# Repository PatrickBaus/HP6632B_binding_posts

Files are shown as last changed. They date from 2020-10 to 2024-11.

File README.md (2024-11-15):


# HP 66332A and HP 6632B-6634B Frontpanel Binding Post PCB
This repository contains the schematics for a PCB to mount frontpanel binding post on an [HP 6632B](https://www.keysight.com/us/en/product/6632B/100-watt-system-power-supply-20v-5a.html) (and siblings) power supply. It is an adaption of the original A4 PCB used in option #020 units.

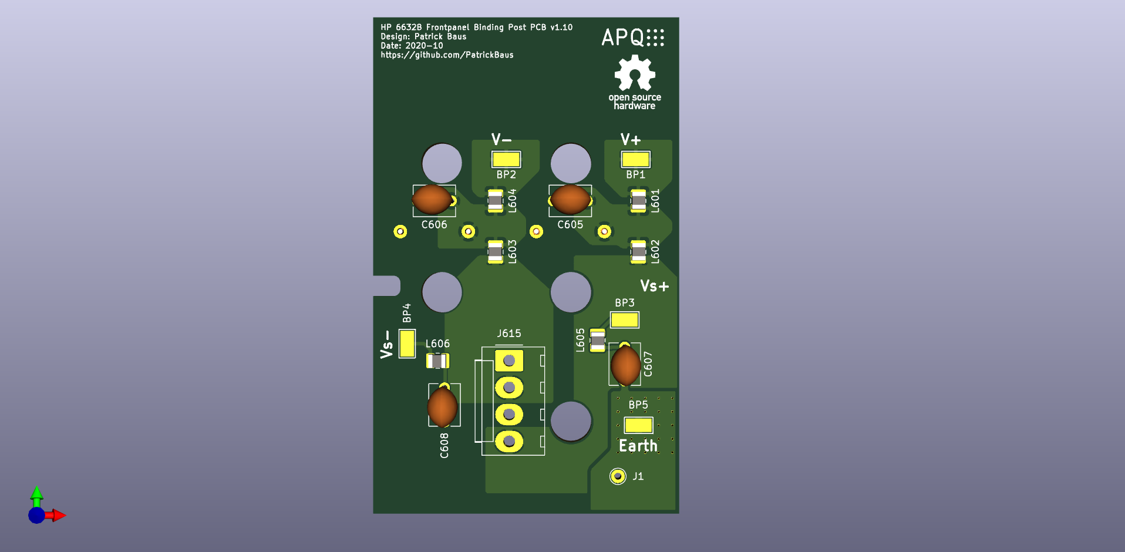
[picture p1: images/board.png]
Front panel binding post PCB


## Contents
- [Introduction](#introduction)
- [Design Files](#design-files)
- [Related Repositories](#related-repositories)
- [Versioning](#versioning)
- [License](#license)

## Introduction
In addition to the original option #20 PCB, this board breaks out the sense connections as well and also the chassis ground. This makes connecting multiple [HP 663xB](https://www.keysight.com/us/en/product/6632B/100-watt-system-power-supply-20v-5a.html) in parallel possible. On the downside, this requires connecting the sense pins externally. To make this easier I also made a small [shorting bar](https://github.com/PatrickBaus/HP6632B_shorting_bar) to easily short the sense terminals to the force terminals directly at the power supply output.

The components chosen allow the board to be used on all variants of the HP 663xB family - even the 100 V 6634B. A variety of different binding posts can be used. There are HP/Agilent versions available on Ebay. I used [Pomona 4243-0](https://www.pomonaelectronics.com/products/hardware/double-binding-post) ([Digikey](https://www.digikey.de/product-detail/de/pomona-electronics/4243-0/501-1126-ND/604321)) and [3760-5](https://www.pomonaelectronics.com/products/hardware/binding-post-tin-plated) ([Digikey](https://www.digikey.de/product-detail/de/pomona-electronics/3760-5/501-1506-ND/736554)) binding posts.

The final result looks like this:
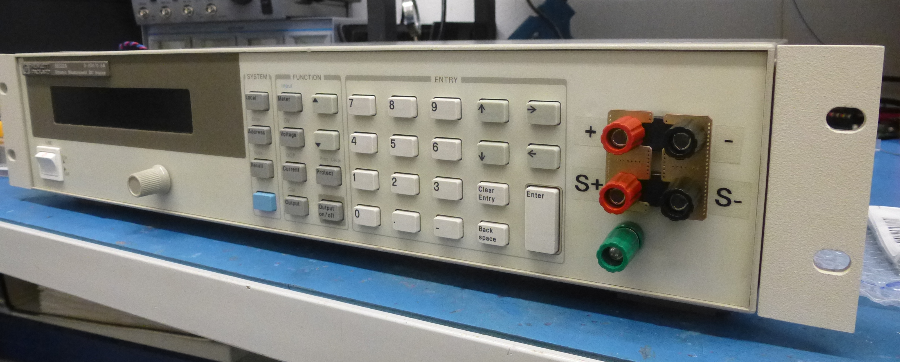
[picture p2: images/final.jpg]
HP 66332A with binding posts


## Design Files
The root folder contains the KiCAD files. The bill of materials can be found on the [releases](../../releases) page along with Gerber files for production.

## Related Repositories
See the following repositories which contain addional optional parts.

- [HP 66332A and HP 6632B-6634B Shorting Bar](https://github.com/PatrickBaus/HP6632B_shorting_bar)

## Versioning
I use [SemVer](http://semver.org/) for versioning. For the versions available, see the [tags](../../tags) available for this repository.

- MAJOR versions in this context mean a breaking change to the external interface of the hardware like different connectors or functions.
- MINOR versions contain changes to the hardware that only affect the inner workings of the circuit, but otherwise the performance is unaffected.
- PATCH versions do not affect the schematics or invalidate older bill of materials. These changes may include updated components (to replace obsolete parts for example), an updated silkscreen, or fixed typos.

## License
This work is released under the CERN-OHL-W
See [https://ohwr.org/cern_ohl_w_v2.pdf](https://ohwr.org/cern_ohl_w_v2.pdf) or the included LICENSE file for more information.

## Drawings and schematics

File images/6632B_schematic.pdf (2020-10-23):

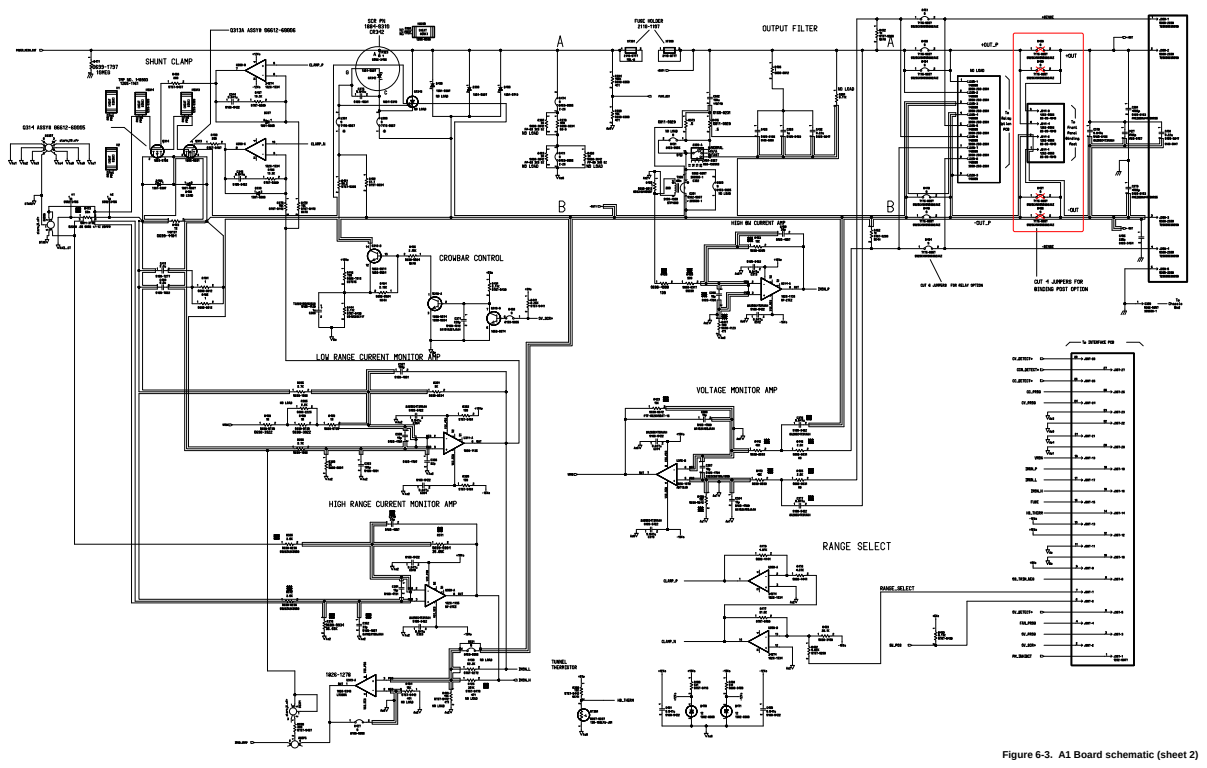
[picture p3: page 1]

Figure 6-3. A1 Board schematic (sheet 2)

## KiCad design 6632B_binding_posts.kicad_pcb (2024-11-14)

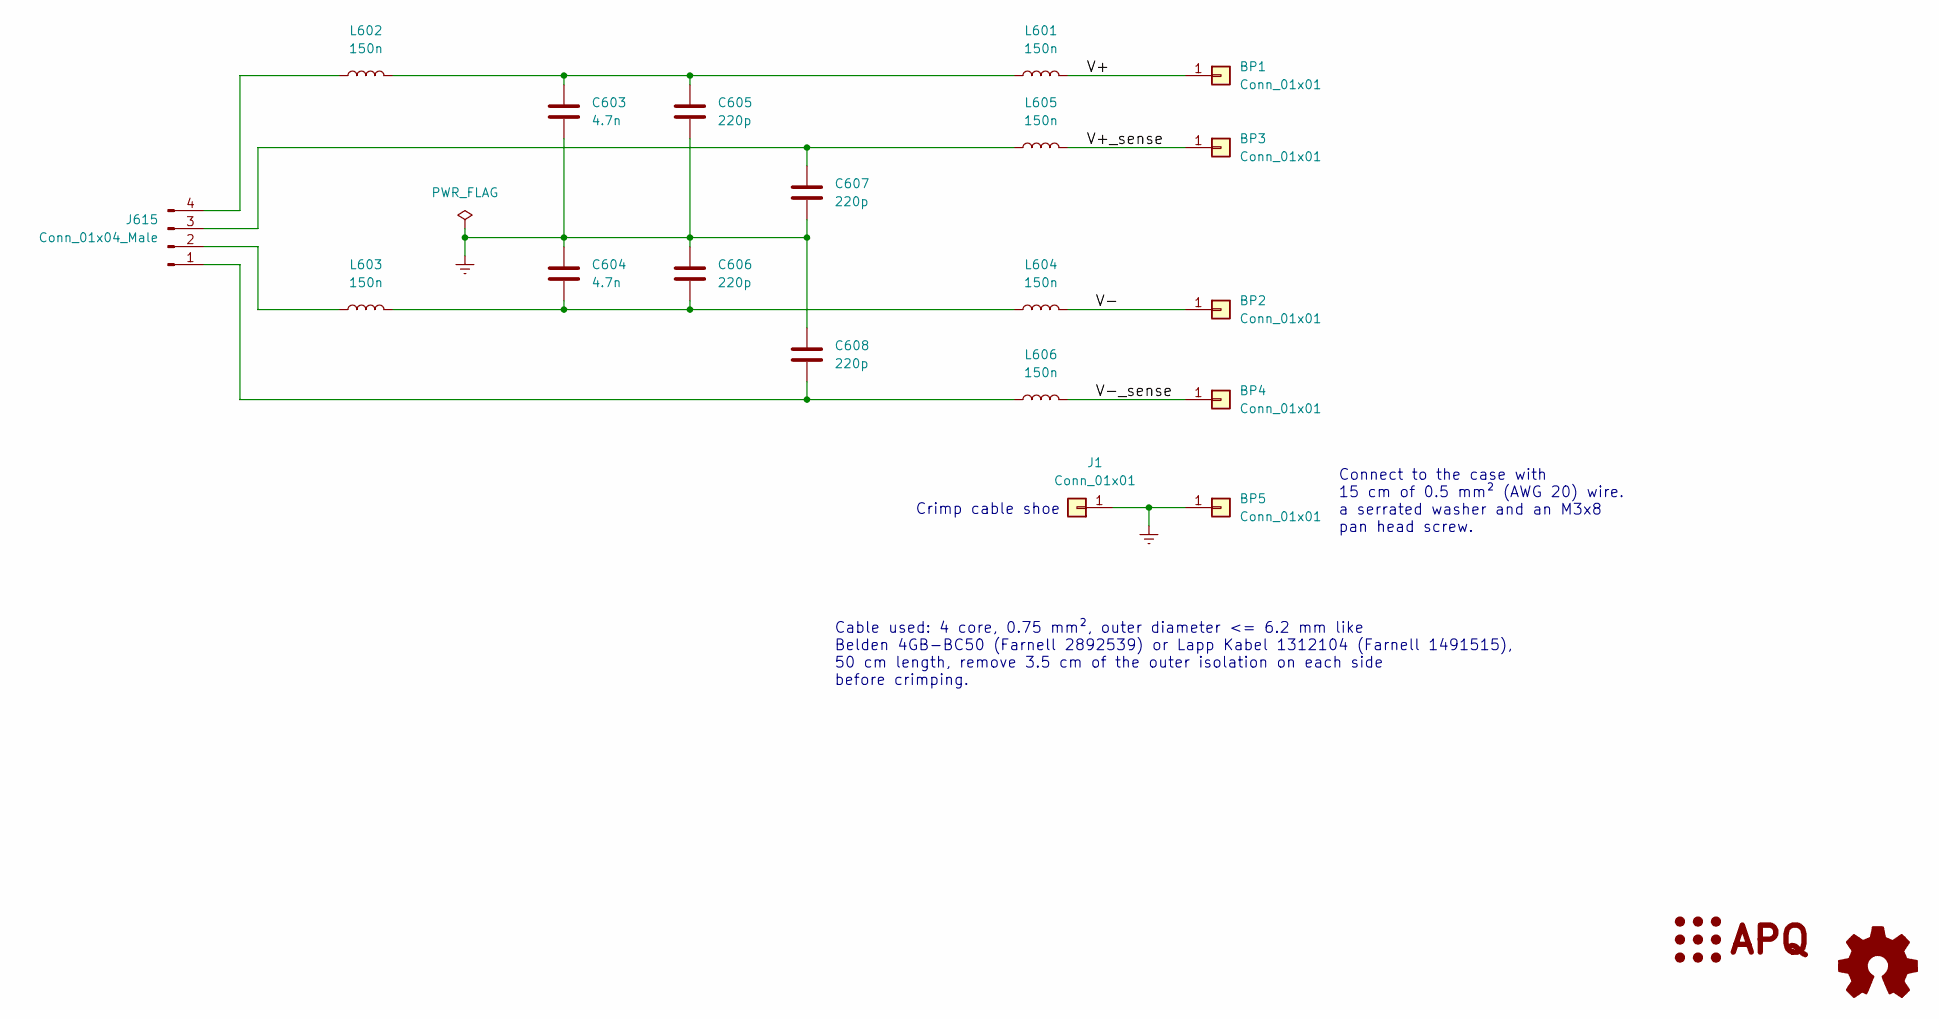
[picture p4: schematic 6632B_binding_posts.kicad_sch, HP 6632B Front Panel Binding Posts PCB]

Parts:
BP1, BP2, BP3, BP4, BP5: Conn_01x01; TestPoint_Keystone_5019_Minature
C603, C604: 4.7n; C_Rect_L13.0mm_W5.0mm_P10.00mm_FKS3_FKP3_MKS4
C605, C606, C607, C608: 220p; C_Disc_D6.0mm_W4.4mm_P5.00mm
J1: Conn_01x01; TestPoint_THTPad_D3.0mm_Drill1.5mm
J615: Conn_01x04_Male; Molex_KK-396_A-41791-0004_1x04_P3.96mm_Vertical
L601, L602, L603, L604, L605, L606: 150n; L_1008_2520Metric
LOGO1: Logo_Open_Hardware_Small; OSHW-Logo_7.5x8mm_SilkScreen
LOGO2: Logo_APQ; APQ-Logo_small

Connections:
/V+: BP1.1, L601.2
/V+_sense: BP3.1, L605.2
/V-: BP2.1, L604.2
/V-_sense: BP4.1, L606.2
Earth: BP5.1, C603.2, C604.1, C605.2, C606.1, C607.2, C608.1, J1.1
unnamed: C603.1, C605.1, L601.1, L602.2
unnamed: C604.2, C606.2, L603.2, L604.1
unnamed: C608.2, J615.1, L606.1
unnamed: J615.2, L603.1
unnamed: C607.1, J615.3, L605.1
unnamed: J615.4, L602.1

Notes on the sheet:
Crimp cable shoe
Connect to the case with 15 cm of 0.5 mm² (AWG 20) wire. a serrated washer and an M3x8 pan head screw.
Cable used: 4 core, 0.75 mm², outer diameter <= 6.2 mm like Belden 4GB-BC50 (Farnell 2892539) or Lapp Kabel 1312104 (Farnell 1491515), 50 cm length, remove 3.5 cm of the outer isolation on each side before crimping.

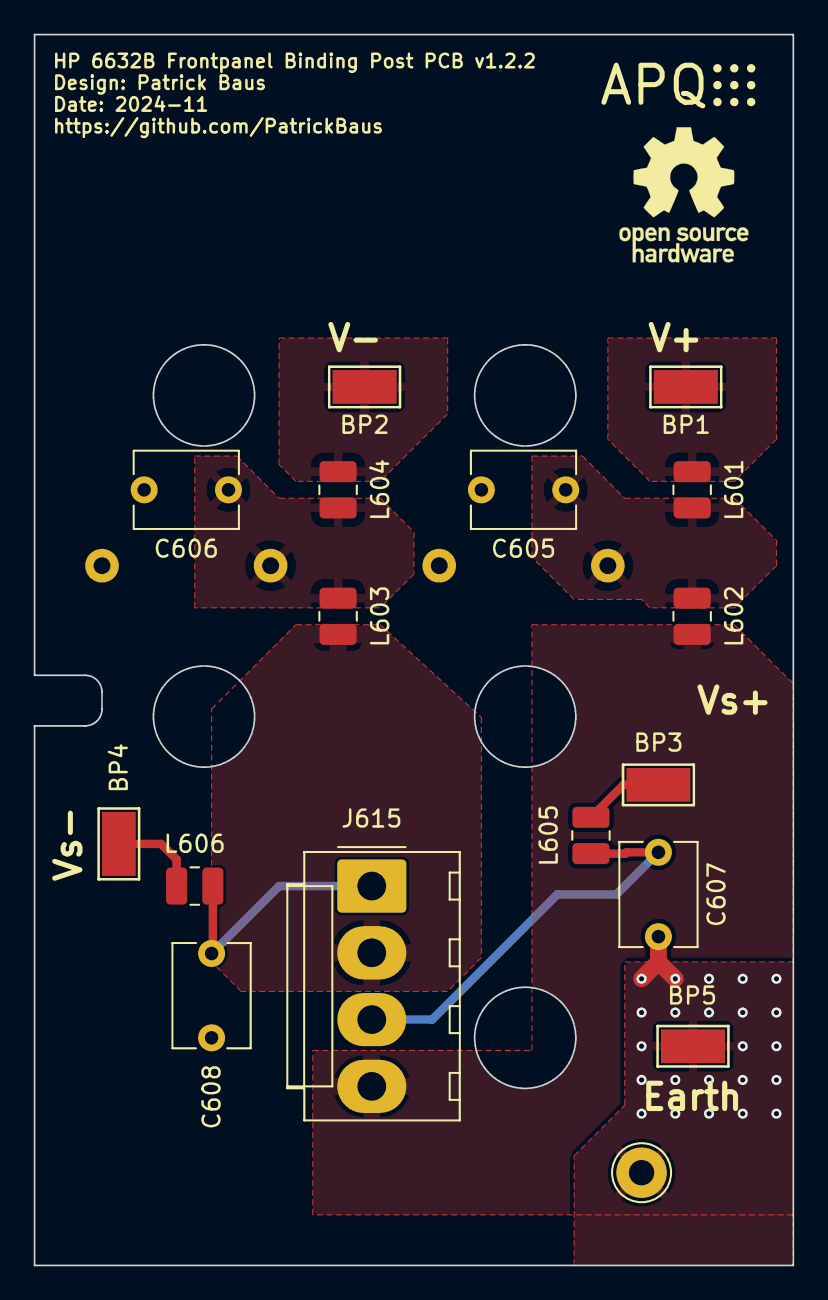
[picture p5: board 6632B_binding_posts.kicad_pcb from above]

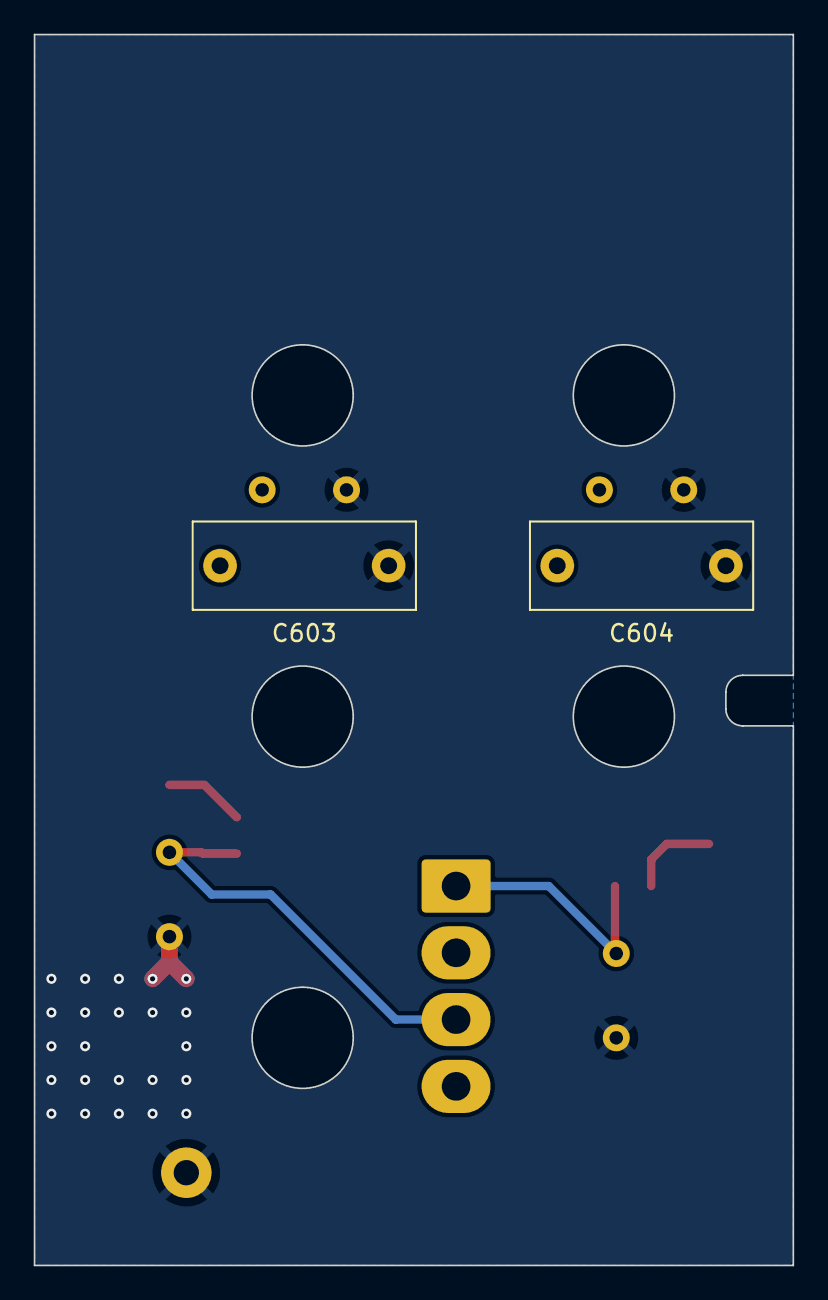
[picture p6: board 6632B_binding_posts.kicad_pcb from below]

Board: 2 copper layers, 45.0 x 73.0 mm, 21 parts (2 on the bottom side), 11 nets.

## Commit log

2020-10-23 Updated to v1.1 Moved cutout 1.5 mm down Decreased size of earth connection J1
    [main-B_Cu.gbr, main-B_Fab.gbr, main-B_Mask.gbr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]
2020-10-23 Added readme Added binding posts to the BOM
    [main.kicad_pcb, main.sch]
2020-10-23 Added BOM and costs file
    [cost.xlsx, main.sch, main_bom_v1.1.csv]
2020-10-23 Added missing crimp connector
    [cost.xlsx, main.sch, main_bom_v1.1.csv]
2021-07-02 Increased GND plane clearance to 0.25 mm
    [main-B_Cu.gbr, main-B_Fab.gbr, main-B_Mask.gbr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]
2024-11-14 Increased drill hole size for the Earth solder connection
    [main.sch]
2024-11-14 Update to KiCad 8
    [main-B_Cu.gbr, main-B_Fab.gbr, main-B_Mask.gbr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]
2024-11-14 Updated license
    [cost.xlsx]
2024-11-14 Renamed source files
    [6632B_binding_posts.kicad_pcb, 6632B_binding_posts.kicad_sch]
2024-11-14 Update logo
    [6632B_binding_posts.kicad_pcb, 6632B_binding_posts.kicad_sch]
2024-11-14 Bump version to 1.1.2
    [6632B_binding_posts.kicad_pcb, 6632B_binding_posts.kicad_sch]
2024-11-14 Reformat version string
    [6632B_binding_posts.kicad_pcb, 6632B_binding_posts.kicad_sch]

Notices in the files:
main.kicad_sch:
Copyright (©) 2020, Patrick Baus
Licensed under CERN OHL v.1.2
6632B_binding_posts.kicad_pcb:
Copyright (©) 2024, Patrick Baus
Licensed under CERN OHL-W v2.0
